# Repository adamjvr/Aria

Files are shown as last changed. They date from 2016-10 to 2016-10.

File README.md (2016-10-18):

# Aria
ARM Cortex M4F + WiFi + MPPT Solar Battery Powered module, mBed and Arduino Compatible hardware development platform.
- ARM Cortex M4F 180MHZ STM32F446RET6
- ESP8285 WiFi SoC w/ PCB Antenna
- WiFi
- USB 2.0 Connectivity
- Plenty or GPIO/Serial via the STM32
- Over the air programming and updating
- Lithium Ion Battery Power
- MPPT Solar battery charging
- USB bus power for desktop development
- Over the Air Programming
- Low power
- 2 Year Battery Life w/Single Cell Lithium Battery

Aria 0.1a PCB
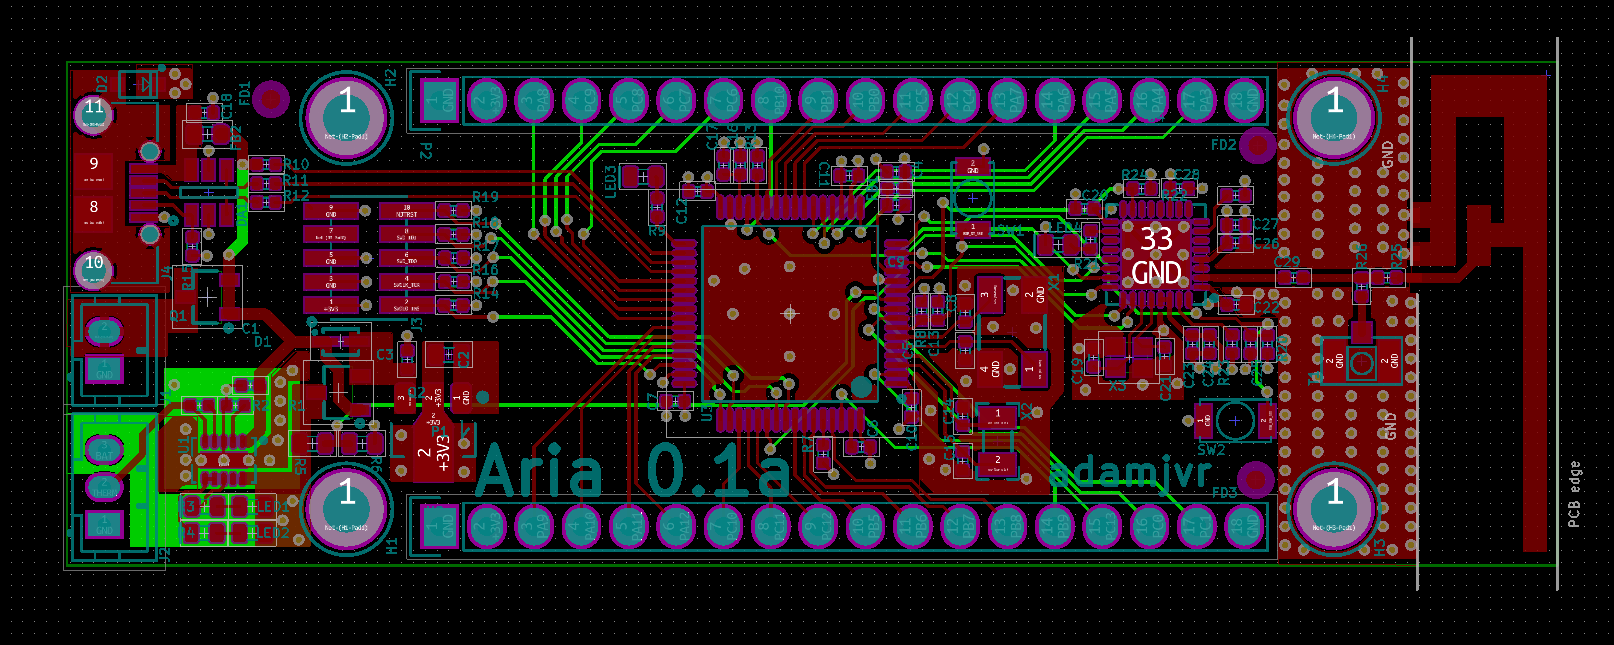
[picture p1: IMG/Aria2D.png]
Aria 0.1a KiCAD PCB

Aria 0.1a 3D Render of PCB
Top
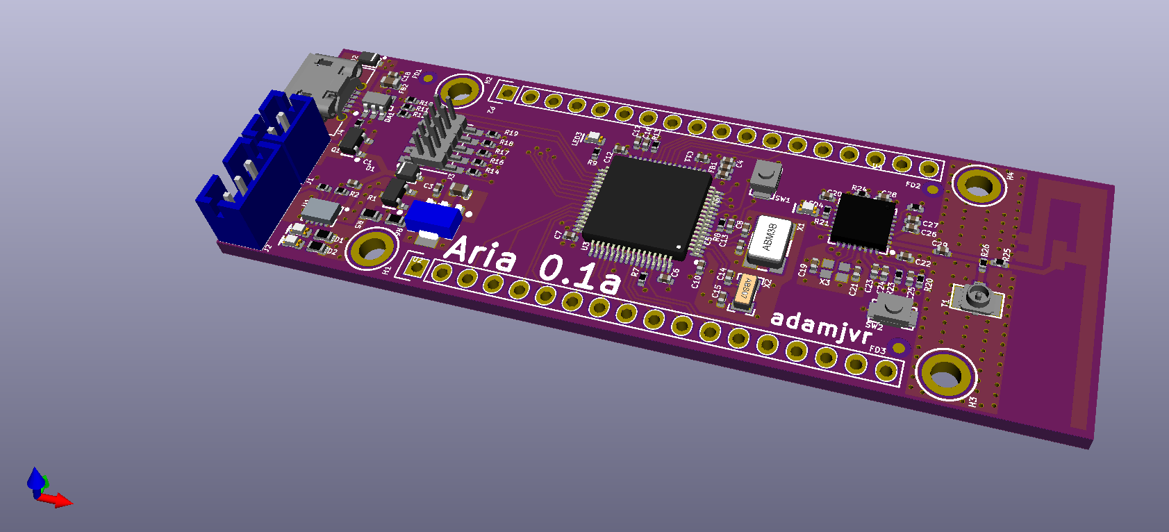
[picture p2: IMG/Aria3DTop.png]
Aria 0.1a KiCAD 3D Top

Bottom
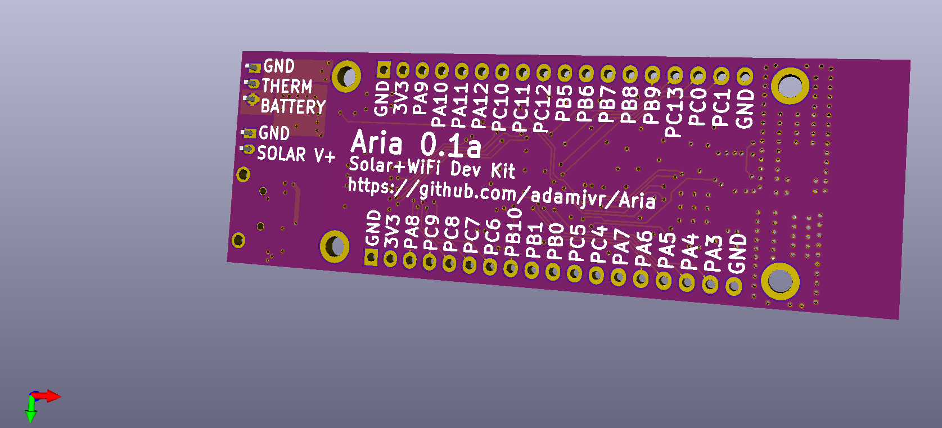
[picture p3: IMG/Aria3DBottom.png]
Aria 0.1a KiCAD 3D Bottom

Aria 0.1a ESP-12E Version PCB
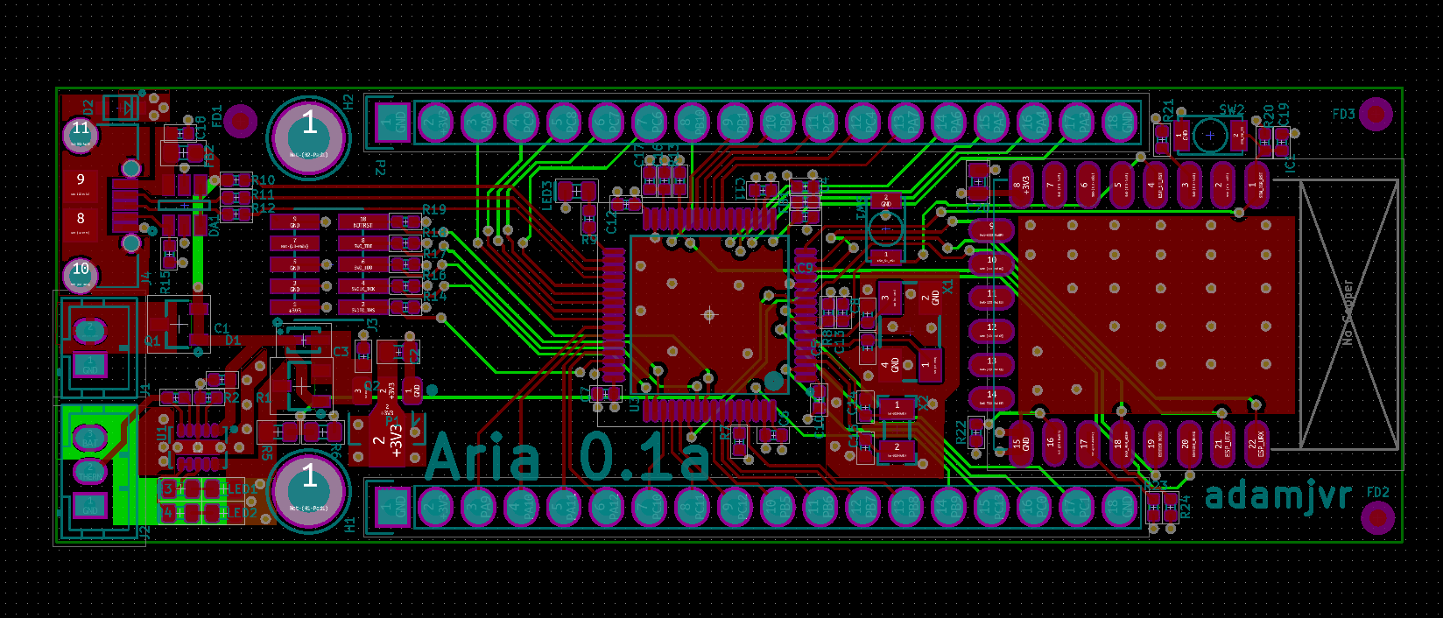
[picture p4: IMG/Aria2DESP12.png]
Aria 0.1a ESP-12E KiCAD PCB


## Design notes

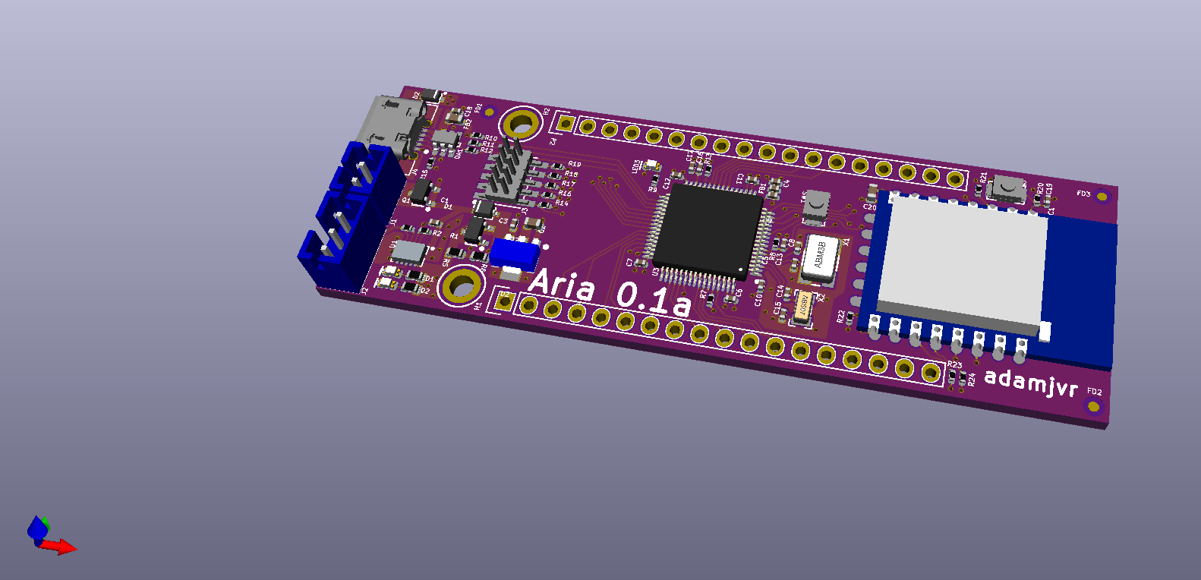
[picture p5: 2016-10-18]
IMG/Aria3DESP12.png

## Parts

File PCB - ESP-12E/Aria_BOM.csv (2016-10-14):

Id | Designator | Package | Quantity | Designation | Supplier and ref
1 | ANT1 | PCB_IF_ANT_2.4G | 1 | Inverted_F_PCB_Antenna
2 | R26,R25 | R0402 | 2 | ERJ-2GE0R00X
3 | R24,R7,R10,R13 | R0402 | 4 | RC1005F103CS
4 | P1,P2 | Socket_Strip_Straight_1x18 | 2 | CONN_01X18
5 | U1 | BQ24210 | 1 | BQ24210DQCT
6 | D1 | BAT20JFILM | 1 | BAT20JFILM
7 | Q1,Q2 | DMG2307L-7 | 2 | DMG2307L-7
8 | X2 | ABS07-32.768KHZ-9-T | 1 | ABS07-32.768KHZ-9-T
9 | D2 | RSB39VTE-17 | 1 | RSB39VTE-17
10 | DA1 | ESDA6V1BC6 | 1 | ESDA6V1BC6
11 | X1 | ABM3B8.000MHZB2T | 1 | ABM3B8.000MHZB2T
12 | FD1,FD2,FD3 | FIDUCIAL | 3 | FIDUCIAL
13 | H2,H4,H1,H3 | M2.5_HOLE | 4 | M2.5_Hole
14 | U3 | STM32F446RET6 | 1 | STM32F446RET6_-_TQFP64
15 | U4 | ESP8285 | 1 | ESP8285
16 | C1,C2 | C0402 | 2 | CL05A105KA5NQNC
17 | C3 | C0603 | 1 | CL10A106KQ8NNNC
18 | C4,C6,C7,C9,C10,C11,C12,C13,C17,C18,C20,C22,C23,C24,C25,C26,C27,C28 | C0402 | 18 | CL05B104JP5NNNC
19 | C5,C8,C19,C21 | C0402 | 4 | CL05C090CB5NNNC
20 | C14,C15 | C0402 | 2 | CL05C180GB5NCNC
21 | C16 | C0402 | 1 | CL05A475KQ5NRNC
22 | FB1 | BLM15HG601SN1D | 1 | BLM15HG601SN1D
23 | FB2 | MI0603K300R-10 | 1 | MI0603K300R-10
24 | J1 | B2B-PH-K-S(LF)(SN) | 1 | B2B-PH-K-S(LF)(SN)
25 | J2 | B3B-PH-K-S(LF)(SN) | 1 | B3B-PH-K-S(LF)(SN)
26 | J3 | 20021121-00010C4LF | 1 | 20021121-00010C4LF
27 | J4 | 0475890001 | 1 | 0475890001-MicroUSBPort
28 | LED1 | LED0603 | 1 | LTST-C191KGKT
29 | LED2 | LED0603 | 1 | LTST-C191KFKT
30 | LED3,LED4 | LED0603 | 2 | LTST-C193TBKT-5A
31 | R1 | R0402 | 1 | RC1005F4870CS
32 | R2,R8,R9,R14,R16,R17,R18,R19,R20,R21 | R0402 | 10 | RC1005F102CS
33 | R3,R4 | R0603 | 2 | RC1608J202CS
34 | R5,R6 | R0603 | 2 | ERA-3AEB3741V
35 | R11,R12 | R0402 | 2 | CPF0402B22RE1
36 | R15 | R0402 | 1 | RC1005J473CS
37 | R22,R23 | R0402 | 2 | RC1005F123CS
38 | SW1,SW2 | B3U-1000P | 2 | B3U-1000P
39 | T1 | 1909763-1 | 1 | 1909763-1
40 | U2 | AZ1117CR-3.3TRG1 | 1 | AZ1117CR-3.3TRG1_1
41 | X3 | FA-128_26.0000MF10Z-AC3 | 1 | FA-128_26.0000MF10Z-AC3

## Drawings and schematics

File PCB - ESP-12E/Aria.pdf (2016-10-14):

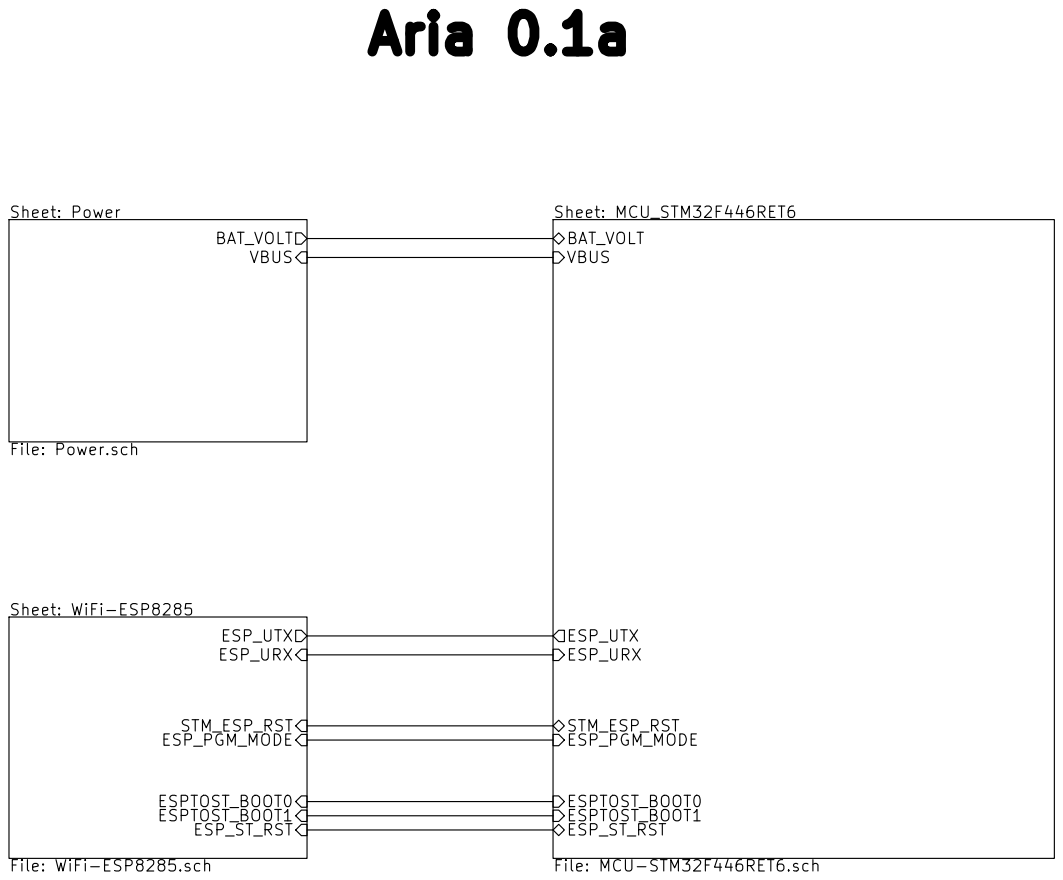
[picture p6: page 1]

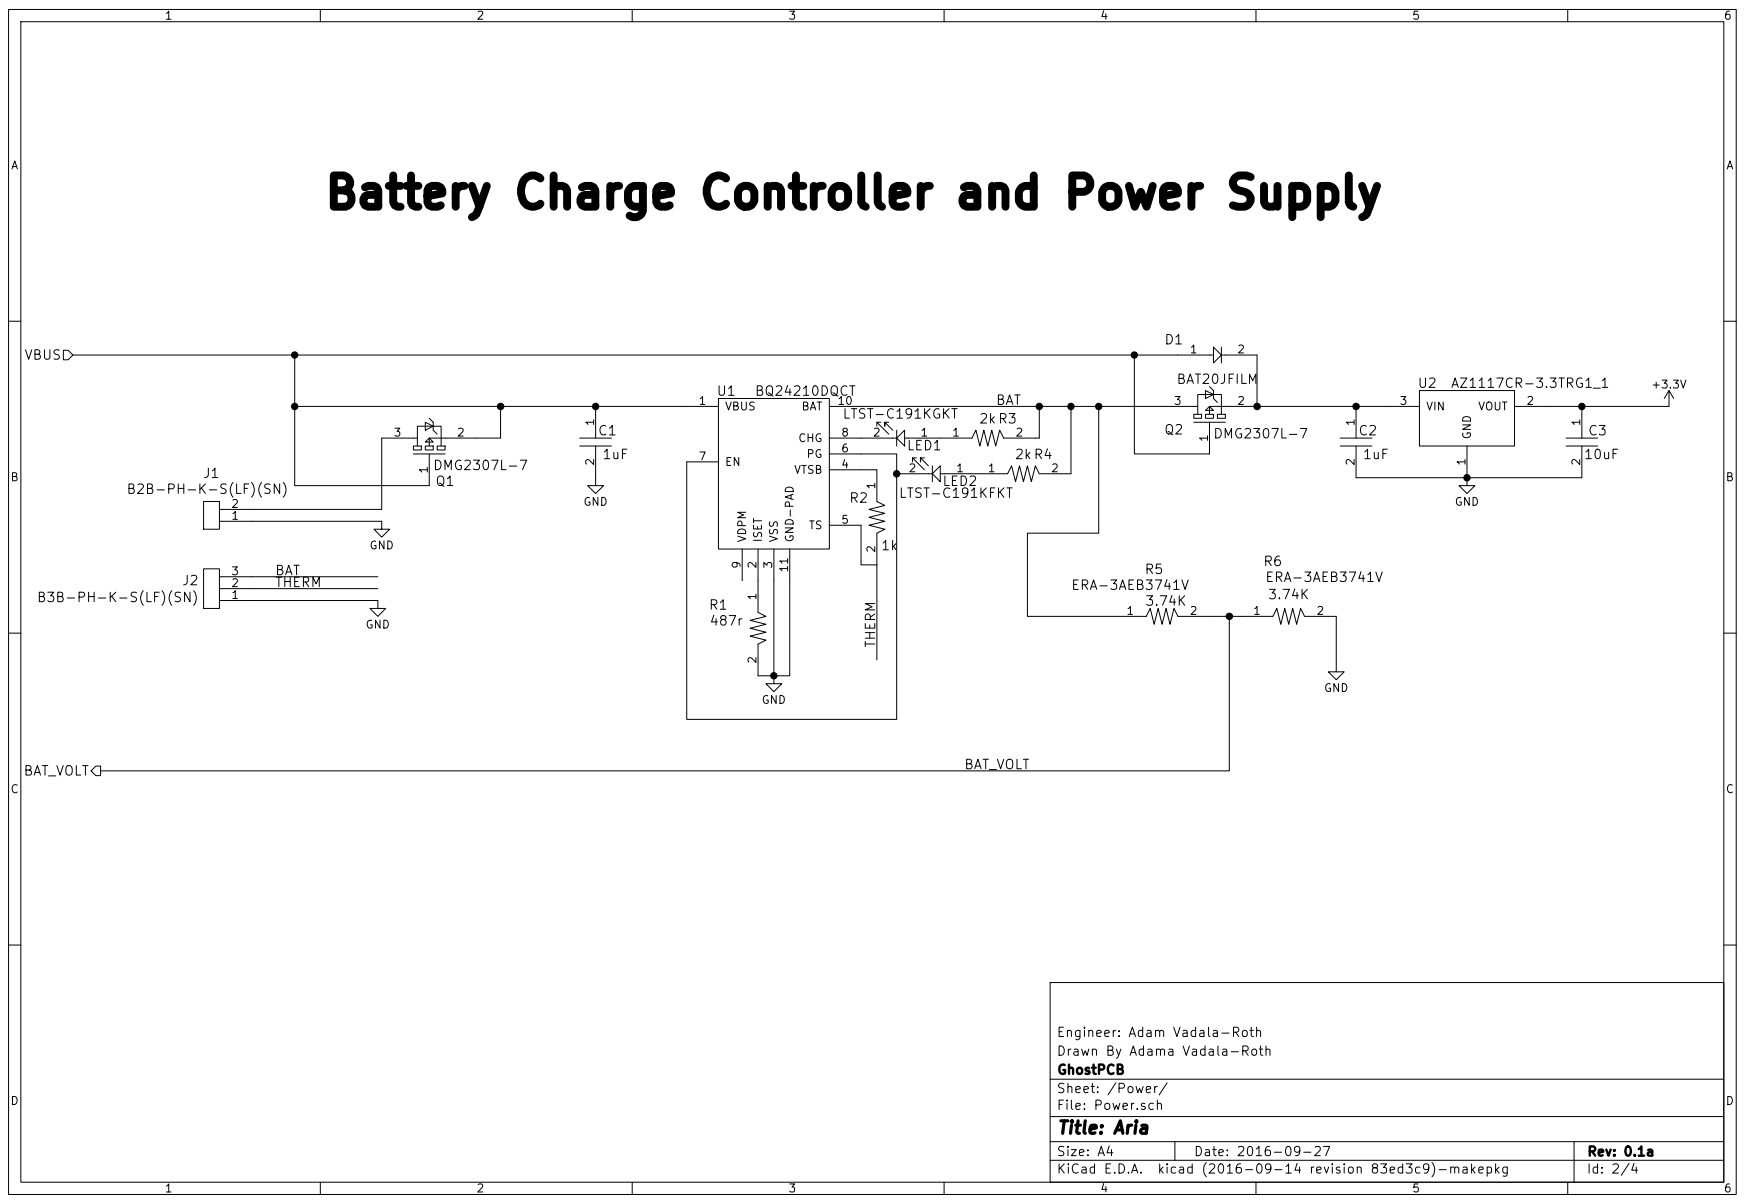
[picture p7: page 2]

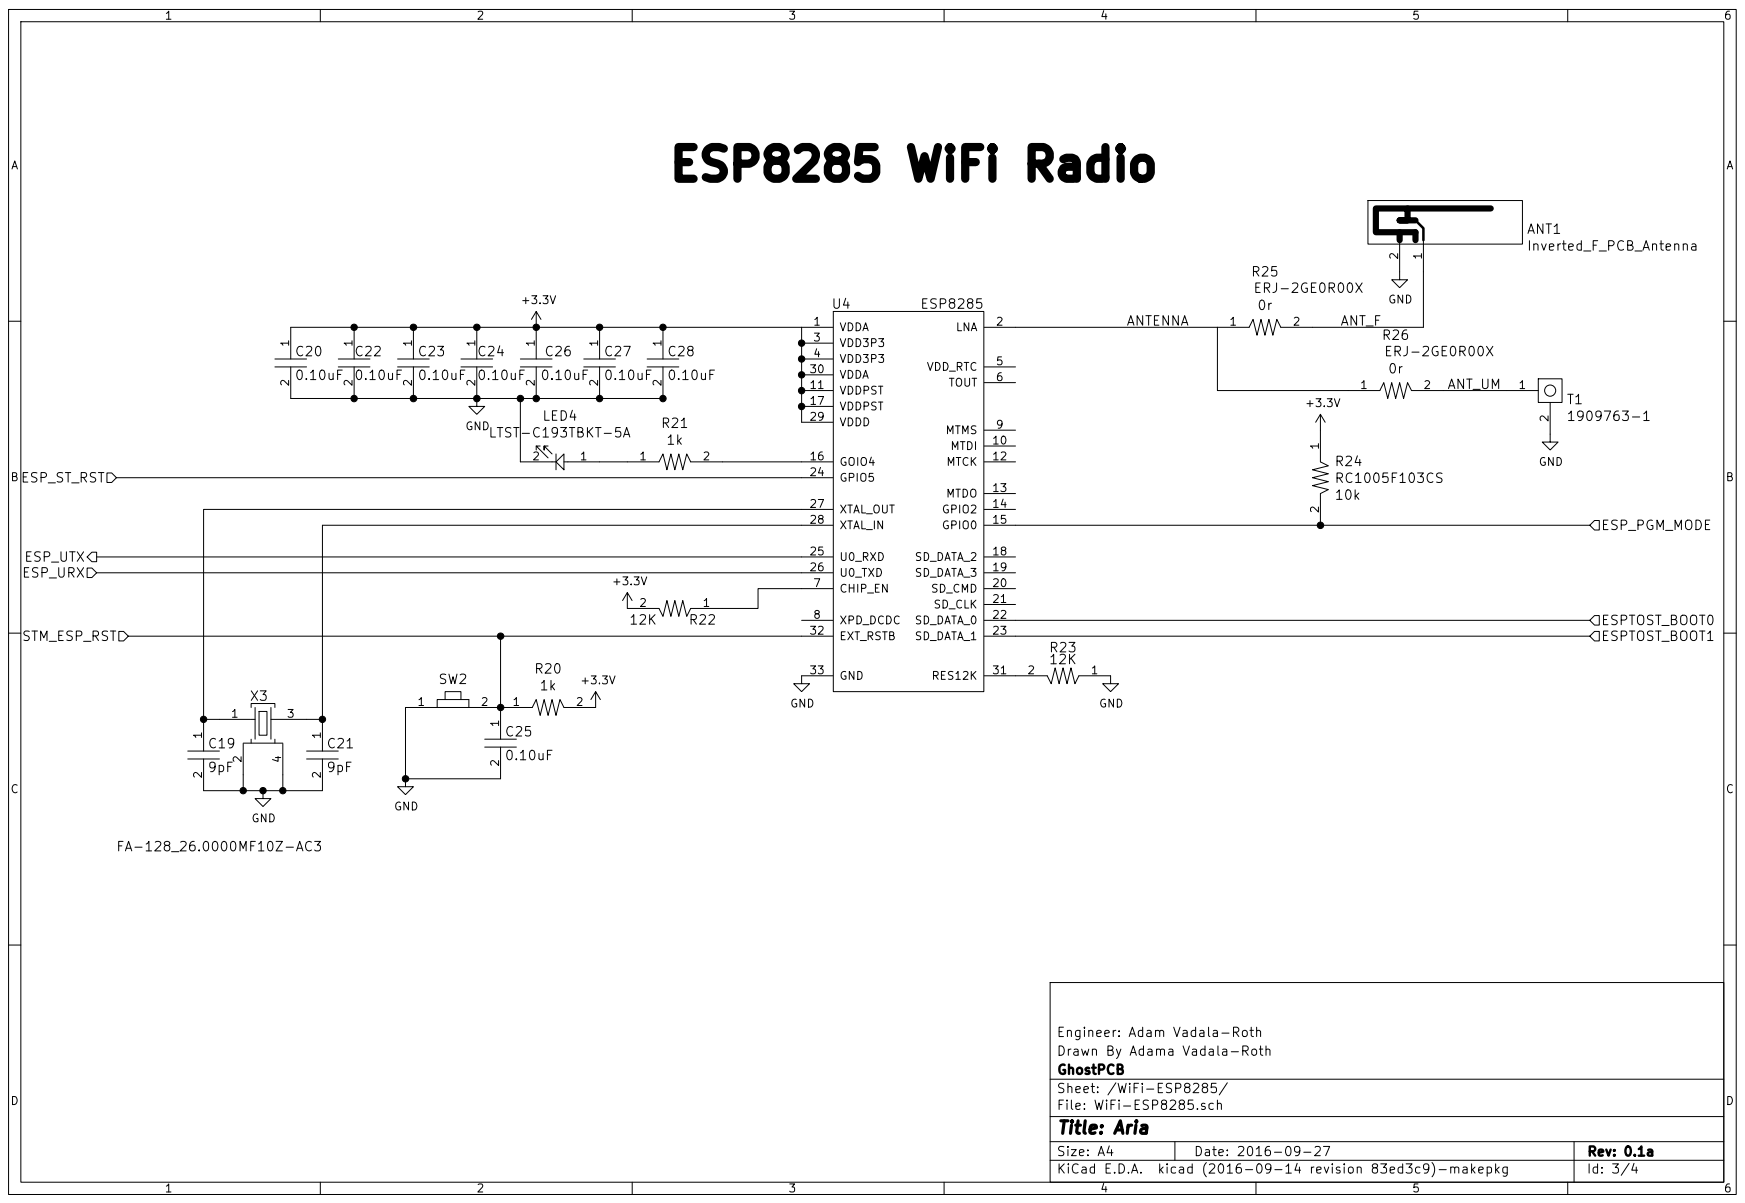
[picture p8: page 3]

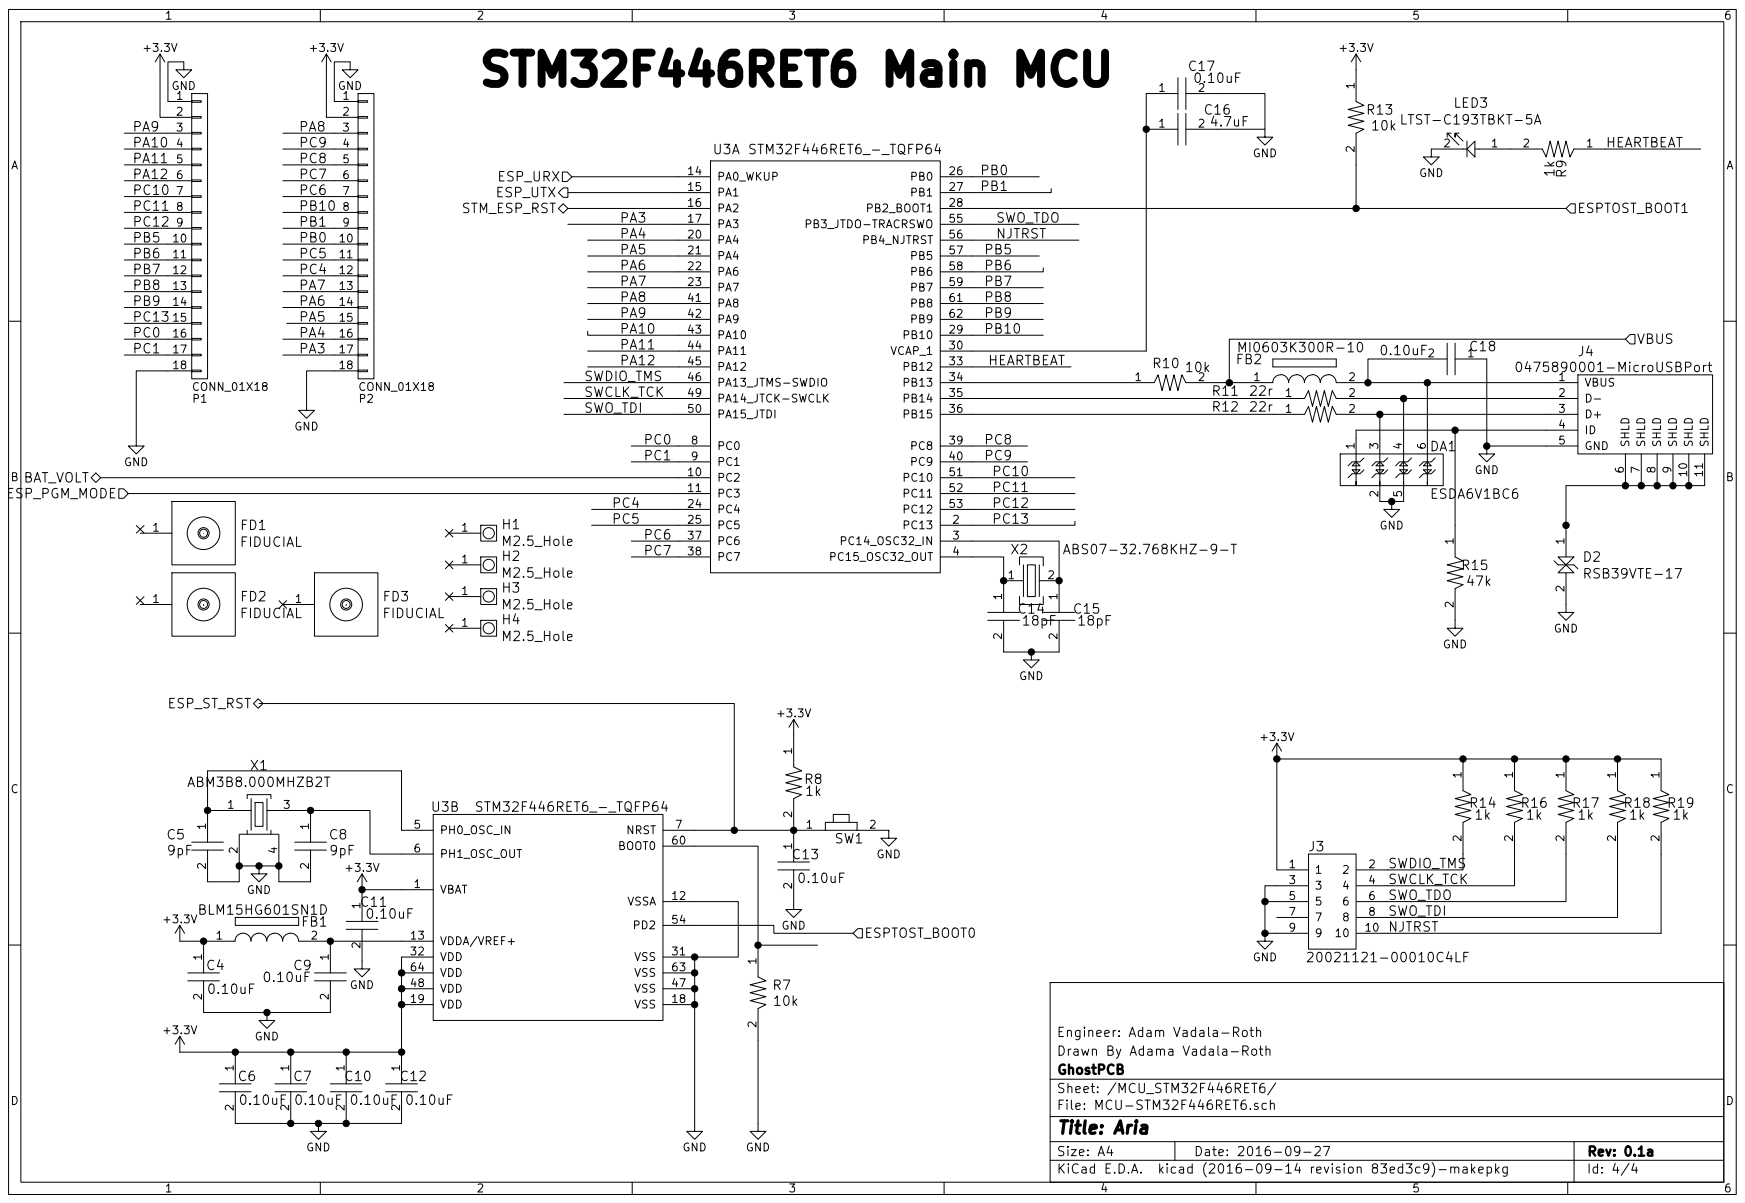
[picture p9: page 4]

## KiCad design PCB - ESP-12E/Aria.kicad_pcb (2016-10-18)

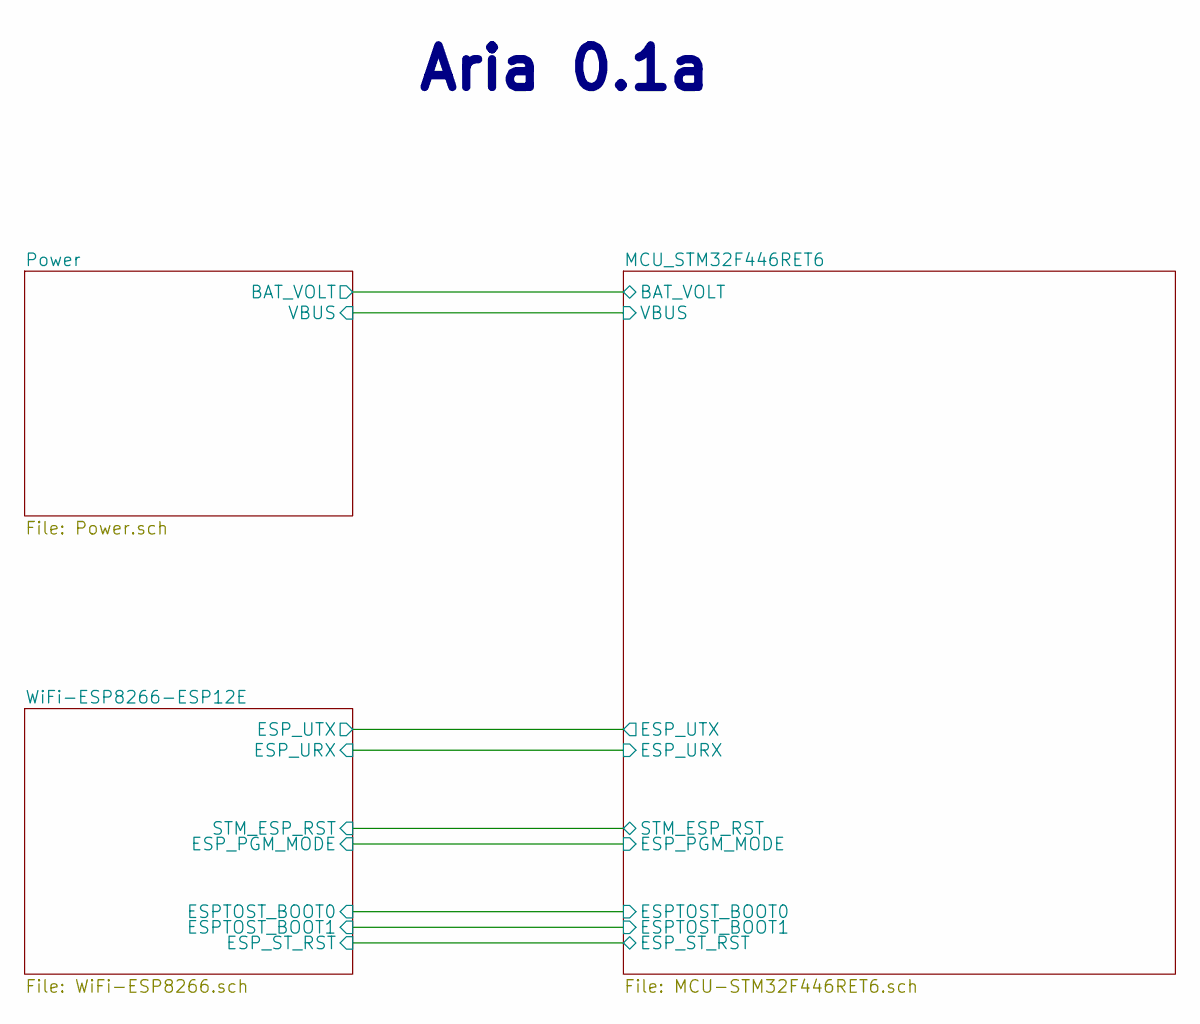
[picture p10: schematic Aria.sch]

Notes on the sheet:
Aria 0.1a

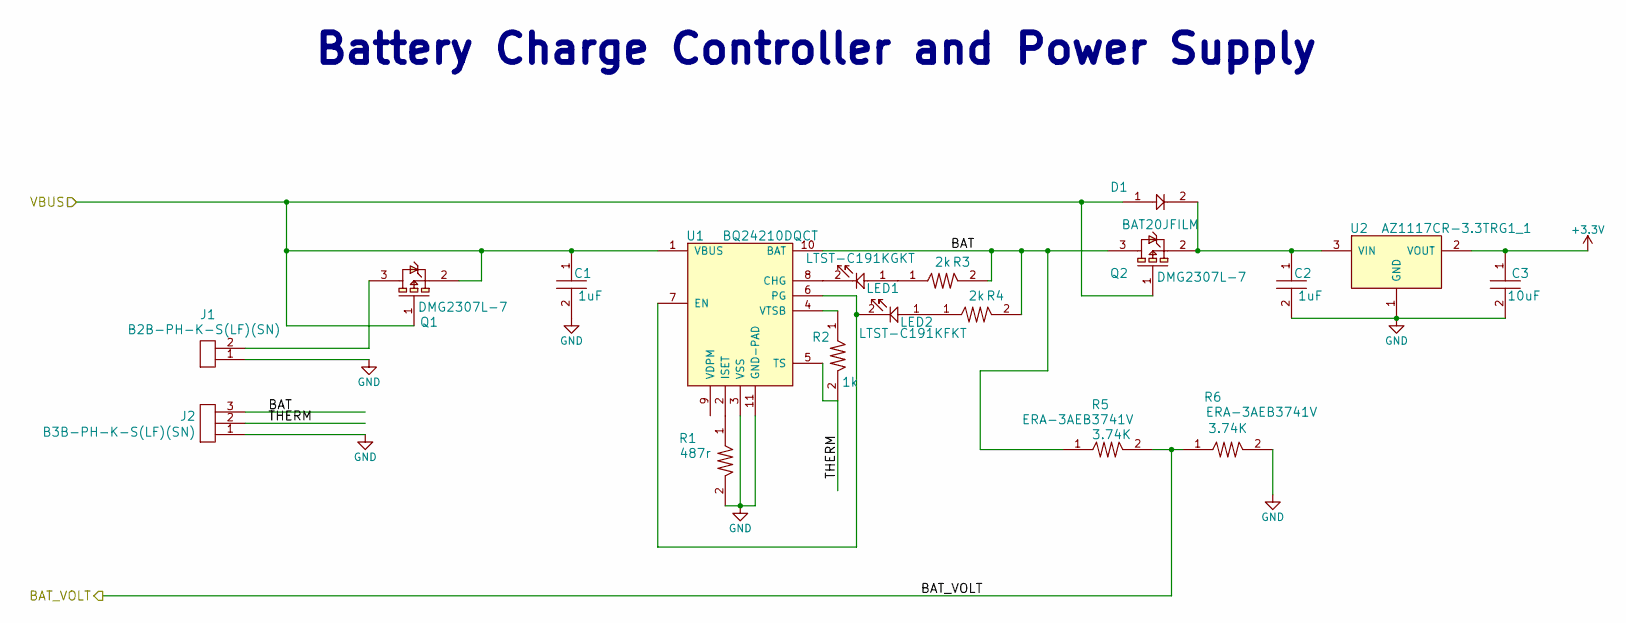
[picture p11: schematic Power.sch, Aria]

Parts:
C1, C2: CL05A105KA5NQNC; C0402; Tolerance 10%; Voltage 25V; MFR# CL05A105KA5NQNC
C3: CL10A106KQ8NNNC; C0603; Tolerance 10%; Voltage 6.3V; MFR# CL10A106KQ8NNNC
D1: BAT20JFILM; Tolerance N/A; Voltage N/A; MFR# BAT20JFILM
J1: B2B-PH-K-S(LF)(SN); Tolerance N/A; Voltage N/A; MFR# B2B-PH-K-S(LF)(SN)
J2: B3B-PH-K-S(LF)(SN); Tolerance N/A; Voltage N/A; MFR# B3B-PH-K-S(LF)(SN)
LED1: LTST-C191KGKT; LED0603; Tolerance N/A; Voltage N/A; MFR# LTST-C191KGKT
LED2: LTST-C191KFKT; LED0603; Tolerance N/A; Voltage N/A; MFR# LTST-C191KFKT
Q1, Q2: DMG2307L-7; Tolerance N/A; Voltage 30V; MFR# DMG2307L-7
R1: RC1005F4870CS; R0402; Tolerance 1%; Voltage N/A; MFR# RC1005F4870CS
R2: RC1005F102CS; R0402; Tolerance %; Voltage N/A; MFR# RC1005F102CS
R3, R4: RC1608J202CS; R0603; Tolerance 1%; Voltage N/A; MFR# RC1608F202CS
R5, R6: ERA-3AEB3741V; R0603; Tolerance 1%; Voltage N/A; MFR# ERA-3AEB3741V
U1: BQ24210DQCT; BQ24210; Tolerance N/A; Voltage 3.5-18VDC; MFR# BQ24210DQCT
U2: AZ1117CR-3.3TRG1_1; AZ1117CR-3.3TRG1; Tolerance N/A; Voltage 3.7V input 3.3V Output; MFR# AZ1117CR-3.3TRG1

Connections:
+3V3: C3.1, U2.2 (VOUT); also elsewhere on the board
/MCU_STM32F446RET6/BAT_VOLT: R5.2, R6.1; also elsewhere on the board
/MCU_STM32F446RET6/VBUS: C1.1, D1.1, Q1.1, Q1.2, Q2.1, U1.1 (VBUS); also elsewhere on the board
/Power/BAT: J2.3, Q2.3, R3.2, R4.2, R5.1, U1.10 (BAT)
/Power/THERM: J2.2, R2.2, U1.5 (TS)
GND: C1.2, C2.2, C3.2, J1.1, J2.1, R1.2, R6.2, U1.3 (VSS), U1.11 (GND-PAD), U2.1 (GND); also elsewhere on the board
unnamed: C2.1, D1.2, Q2.2, U2.3 (VIN)
unnamed: J1.2, Q1.3
unnamed: LED1.1, R3.1
unnamed: LED1.2, U1.8 (CHG)
unnamed: LED2.1, R4.1
unnamed: LED2.2, U1.6 (PG), U1.7 (EN)
unnamed: R1.1, U1.2 (ISET)
unnamed: R2.1, U1.4 (VTSB)

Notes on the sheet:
Battery Charge Controller and Power Supply

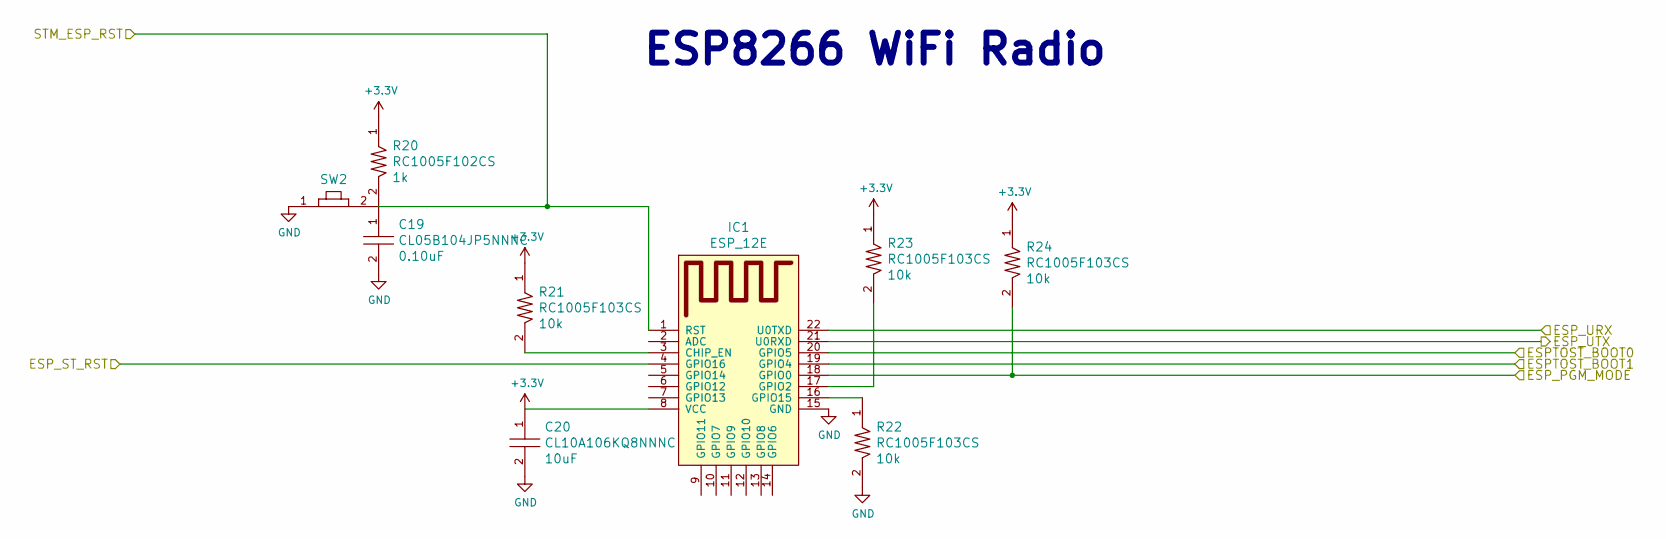
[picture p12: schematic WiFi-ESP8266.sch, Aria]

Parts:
C19: CL05B104JP5NNNC; C0402; Tolerance 5%; Voltage 10V; MFR# CL05B104JP5NNNC
C20: CL10A106KQ8NNNC; C0603; Tolerance 10%; Voltage 6.3V; MFR# CL10A106KQ8NNNC
IC1: ESP_12E; ESP-12E
R20: RC1005F102CS; R0402; Tolerance %; Voltage N/A; MFR# RC1005F102CS
R21, R22, R23, R24: RC1005F103CS; R0402; Tolerance 1%; Voltage N/A; MFR# RC1005F103CS
SW2: B3U-1000P; Tolerance %; Voltage 50V; MFR# B3U-1000P

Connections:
+3V3: C20.1, IC1.8 (VCC), R20.1, R21.1, R23.1, R24.1; also elsewhere on the board
/MCU_STM32F446RET6/ESPTOST_BOOT0: IC1.20 (GPIO5); also elsewhere on the board
/MCU_STM32F446RET6/ESPTOST_BOOT1: IC1.19 (GPIO4); also elsewhere on the board
/MCU_STM32F446RET6/ESP_PGM_MODE: IC1.18 (GPIO0), R24.2; also elsewhere on the board
/MCU_STM32F446RET6/ESP_ST_RST: IC1.4 (GPIO16); also elsewhere on the board
/MCU_STM32F446RET6/ESP_URX: IC1.22 (U0TXD); also elsewhere on the board
/MCU_STM32F446RET6/ESP_UTX: IC1.21 (U0RXD); also elsewhere on the board
/MCU_STM32F446RET6/STM_ESP_RST: C19.1, IC1.1 (RST), R20.2, SW2.2; also elsewhere on the board
GND: C19.2, C20.2, IC1.15 (GND), R22.2, SW2.1; also elsewhere on the board
unnamed: IC1.3 (CHIP_EN), R21.2
unnamed: IC1.16 (GPIO15), R22.1
unnamed: IC1.17 (GPIO2), R23.2

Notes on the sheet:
ESP8266 WiFi Radio

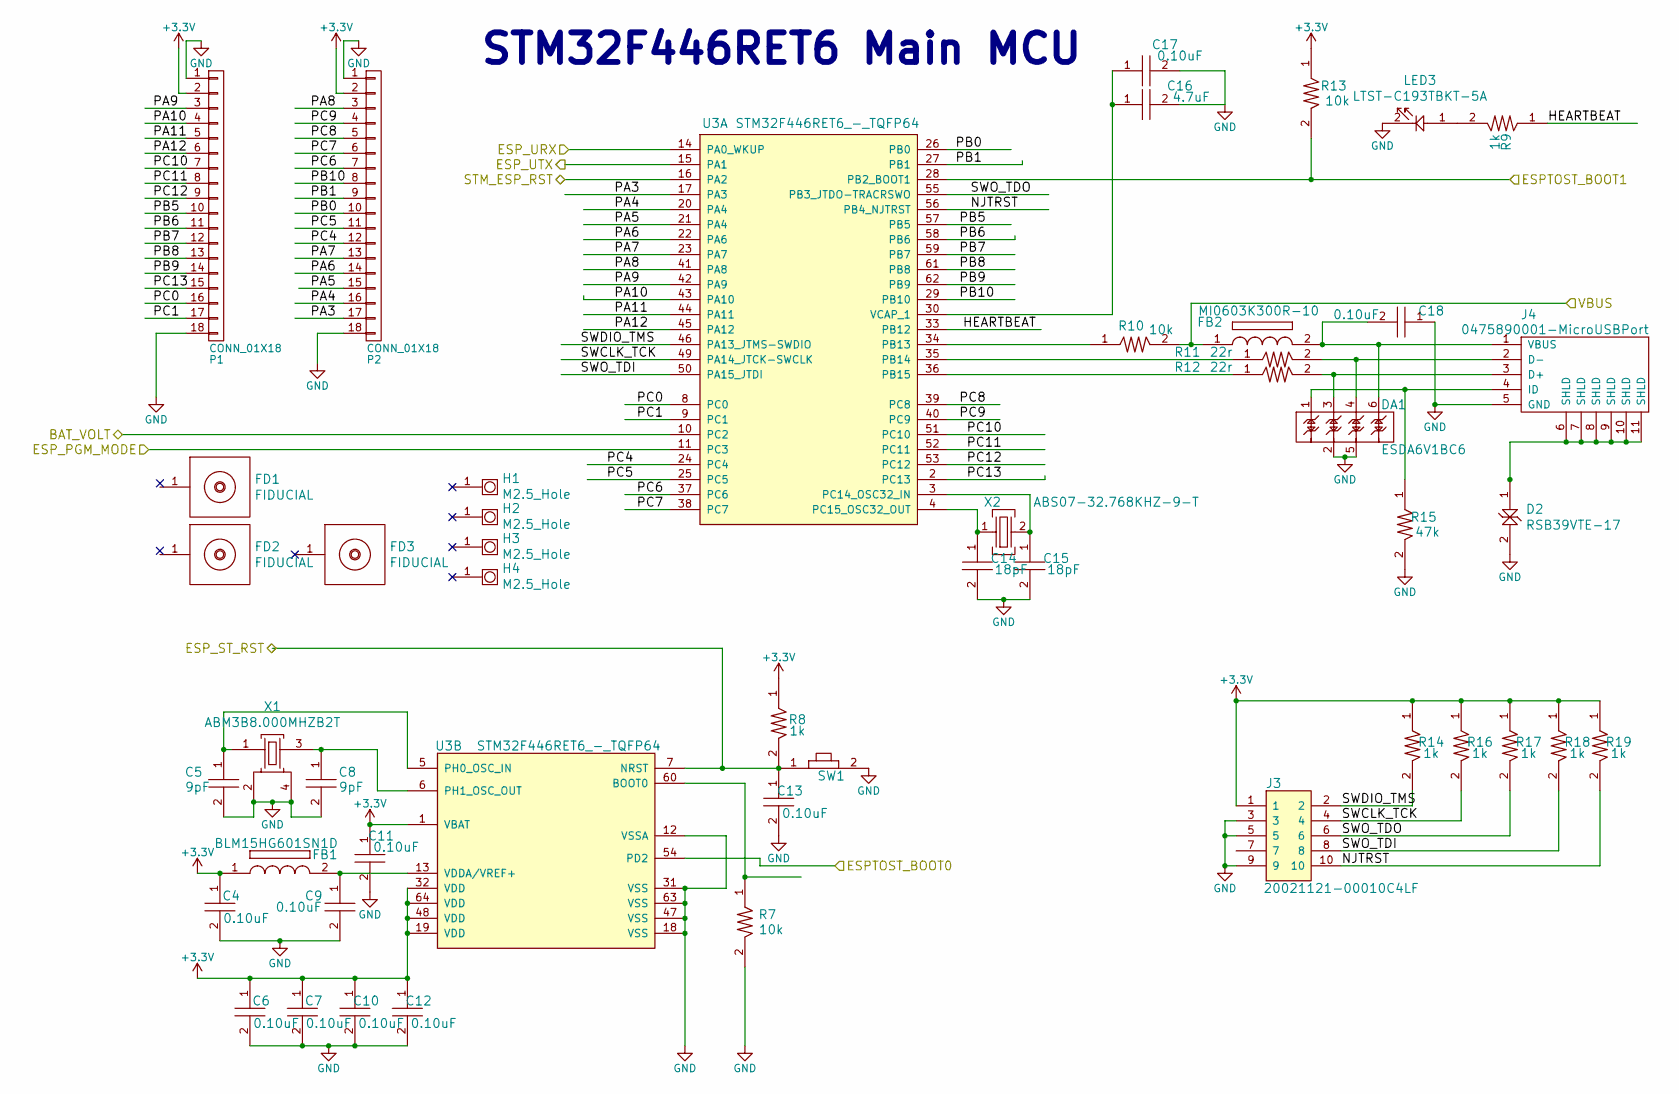
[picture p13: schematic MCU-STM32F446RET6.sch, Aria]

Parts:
C4, C6, C7, C9, C10, C11, C12, C13, C17, C18: CL05B104JP5NNNC; C0402; Tolerance 5%; Voltage 10V; MFR# CL05B104JP5NNNC
C5, C8: CL05C090CB5NNNC; C0402; Tolerance 0.25pF; Voltage 50V; MFR# CL05C090CB5NNNC
C14, C15: CL05C180GB5NCNC; C0402; Tolerance 2%; Voltage 50V; MFR# CL05C180GB5NCNC
C16: CL05A475KQ5NRNC; C0402; Tolerance 10%; Voltage 25V; MFR# CL05A475KQ5NRNC
D2: RSB39VTE-17; Tolerance N/A; Voltage 30V; MFR# RSB39VTE-17
DA1: ESDA6V1BC6; Tolerance N/A; Voltage 4V; MFR# ESDA6V1BC6
FB1: BLM15HG601SN1D; Tolerance N/A; Voltage N/A; MFR# BLM15HG601SN1D
FB2: MI0603K300R-10; Tolerance N/A; Voltage N/A; MFR# MI0603K300R-10
FD1, FD2, FD3: FIDUCIAL
H1, H2, H3, H4: M2.5_Hole; M2.5_HOLE
J3: 20021121-00010C4LF; Tolerance N/A; Voltage 200V MAX; MFR# 20021121-00010C4LF
J4: 0475890001-MicroUSBPort; 0475890001; Tolerance N/A; Voltage 5V; MFR# 0475890001
LED3: LTST-C193TBKT-5A; LED0603; Tolerance N/A; Voltage 2.8V Forward Voltage; MFR# LTST-C193TBKT-5A
P1, P2: CONN_01X18
R7, R10, R13: RC1005F103CS; R0402; Tolerance 1%; Voltage N/A; MFR# RC1005F103CS
R8, R9, R14, R16, R17, R18, R19: RC1005F102CS; R0402; Tolerance %; Voltage N/A; MFR# RC1005F102CS
R11, R12: CPF0402B22RE1; R0402; Tolerance 0.1%; Voltage N/A; MFR# CPF0402B22RE1
R15: RC1005J473CS; R0402; Tolerance 5%; Voltage N/A; MFR# RC1005J473CS
SW1: B3U-1000P; Tolerance %; Voltage 50V; MFR# B3U-1000P
U3: STM32F446RET6_-_TQFP64; STM32F446RET6; Tolerance N/A; Voltage 1.8-3.3V; MFR# STM32F446RET6
X1: ABM3B8.000MHZB2T; Tolerance N/A; Voltage 3.3V; MFR# ABM3B-8.000MHZ-B2-T
X2: ABS07-32.768KHZ-9-T; Tolerance ±20ppm; Voltage N/A; MFR# ABS07-32.768KHZ-9-T

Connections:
+3V3: C4.1, C6.1, C7.1, C10.1, C11.1, C12.1, FB1.1, J3.1, P1.2, P2.2, R8.1, R13.1, R14.1, R16.1, R17.1, R18.1, R19.1, U3.1 (VBAT), U3.19 (VDD), U3.32 (VDD), U3.48 (VDD), U3.64 (VDD); also elsewhere on the board
/MCU_STM32F446RET6/BAT_VOLT: U3.10 (PC2); also elsewhere on the board
/MCU_STM32F446RET6/ESPTOST_BOOT0: U3.54 (PD2); also elsewhere on the board
/MCU_STM32F446RET6/ESPTOST_BOOT1: R13.2, U3.28 (PB2_BOOT1); also elsewhere on the board
/MCU_STM32F446RET6/ESP_PGM_MODE: U3.11 (PC3); also elsewhere on the board
/MCU_STM32F446RET6/ESP_ST_RST: C13.1, R8.2, SW1.1, U3.7 (NRST); also elsewhere on the board
/MCU_STM32F446RET6/ESP_URX: U3.14 (PA0_WKUP); also elsewhere on the board
/MCU_STM32F446RET6/ESP_UTX: U3.15 (PA1); also elsewhere on the board
/MCU_STM32F446RET6/HEARTBEAT: R9.1, U3.33 (PB12)
/MCU_STM32F446RET6/NJTRST: J3.10, R19.2, U3.56 (PB4_NJTRST)
/MCU_STM32F446RET6/PA3: P2.17, U3.17 (PA3)
/MCU_STM32F446RET6/PA4: P2.16, U3.20 (PA4)
/MCU_STM32F446RET6/PA5: P2.15, U3.21 (PA4)
/MCU_STM32F446RET6/PA6: P2.14, U3.22 (PA6)
/MCU_STM32F446RET6/PA7: P2.13, U3.23 (PA7)
/MCU_STM32F446RET6/PA8: P2.3, U3.41 (PA8)
/MCU_STM32F446RET6/PA9: P1.3, U3.42 (PA9)
/MCU_STM32F446RET6/PA10: P1.4, U3.43 (PA10)
/MCU_STM32F446RET6/PA11: P1.5, U3.44 (PA11)
/MCU_STM32F446RET6/PA12: P1.6, U3.45 (PA12)
/MCU_STM32F446RET6/PB0: P2.10, U3.26 (PB0)
/MCU_STM32F446RET6/PB1: P2.9, U3.27 (PB1)
/MCU_STM32F446RET6/PB5: P1.10, U3.57 (PB5)
/MCU_STM32F446RET6/PB6: P1.11, U3.58 (PB6)
/MCU_STM32F446RET6/PB7: P1.12, U3.59 (PB7)
/MCU_STM32F446RET6/PB8: P1.13, U3.61 (PB8)
/MCU_STM32F446RET6/PB9: P1.14, U3.62 (PB9)
/MCU_STM32F446RET6/PB10: P2.8, U3.29 (PB10)
/MCU_STM32F446RET6/PC0: P1.16, U3.8 (PC0)
/MCU_STM32F446RET6/PC1: P1.17, U3.9 (PC1)
/MCU_STM32F446RET6/PC4: P2.12, U3.24 (PC4)
/MCU_STM32F446RET6/PC5: P2.11, U3.25 (PC5)
/MCU_STM32F446RET6/PC6: P2.7, U3.37 (PC6)
/MCU_STM32F446RET6/PC7: P2.6, U3.38 (PC7)
/MCU_STM32F446RET6/PC8: P2.5, U3.39 (PC8)
/MCU_STM32F446RET6/PC9: P2.4, U3.40 (PC9)
/MCU_STM32F446RET6/PC10: P1.7, U3.51 (PC10)
/MCU_STM32F446RET6/PC11: P1.8, U3.52 (PC11)
/MCU_STM32F446RET6/PC12: P1.9, U3.53 (PC12)
/MCU_STM32F446RET6/PC13: P1.15, U3.2 (PC13)
/MCU_STM32F446RET6/STM_ESP_RST: U3.16 (PA2); also elsewhere on the board
/MCU_STM32F446RET6/SWCLK_TCK: J3.4, R16.2, U3.49 (PA14_JTCK-SWCLK)
/MCU_STM32F446RET6/SWDIO_TMS: J3.2, R14.2, U3.46 (PA13_JTMS-SWDIO)
/MCU_STM32F446RET6/SWO_TDI: J3.8, R18.2, U3.50 (PA15_JTDI)
/MCU_STM32F446RET6/SWO_TDO: J3.6, R17.2, U3.55 (PB3_JTDO-TRACRSWO)
/MCU_STM32F446RET6/VBUS: FB2.1, R10.2; also elsewhere on the board
GND: C4.2, C5.2, C6.2, C7.2, C8.2, C9.2, C10.2, C11.2, C12.2, C13.2, C14.2, C15.2, C16.2, C17.2, C18.1, D2.2, DA1.2, DA1.5, J3.3, J3.5, J3.9, J4.5 (GND), LED3.2, P1.1, P1.18, P2.1, P2.18, R7.2, R15.2, SW1.2, U3.12 (VSSA), U3.18 (VSS), U3.31 (VSS), U3.47 (VSS), U3.63 (VSS), X1.2, X1.4; also elsewhere on the board
unnamed: C5.1, U3.5 (PH0_OSC_IN), X1.1
unnamed: C8.1, U3.6 (PH1_OSC_OUT), X1.3
unnamed: C9.1, FB1.2, U3.13 (VDDA/VREF+)
unnamed: C14.1, U3.4 (PC15_OSC32_OUT), X2.1
unnamed: C15.1, U3.3 (PC14_OSC32_IN), X2.2
unnamed: C16.1, C17.1, U3.30 (VCAP_1)
unnamed: C18.2, DA1.6, FB2.2, J4.1 (VBUS)
unnamed: D2.1, J4.6 (SHLD), J4.7 (SHLD), J4.8 (SHLD), J4.9 (SHLD), J4.10 (SHLD), J4.11 (SHLD)
unnamed: DA1.1, J4.4 (ID), R15.1
unnamed: DA1.3, J4.3 (D+), R12.2
unnamed: DA1.4, J4.2 (D-), R11.2
unnamed: LED3.1, R9.2
unnamed: R7.1, U3.60 (BOOT0)
unnamed: R10.1, U3.34 (PB13)
unnamed: R11.1, U3.35 (PB14)
unnamed: R12.1, U3.36 (PB15)

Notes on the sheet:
STM32F446RET6 Main MCU

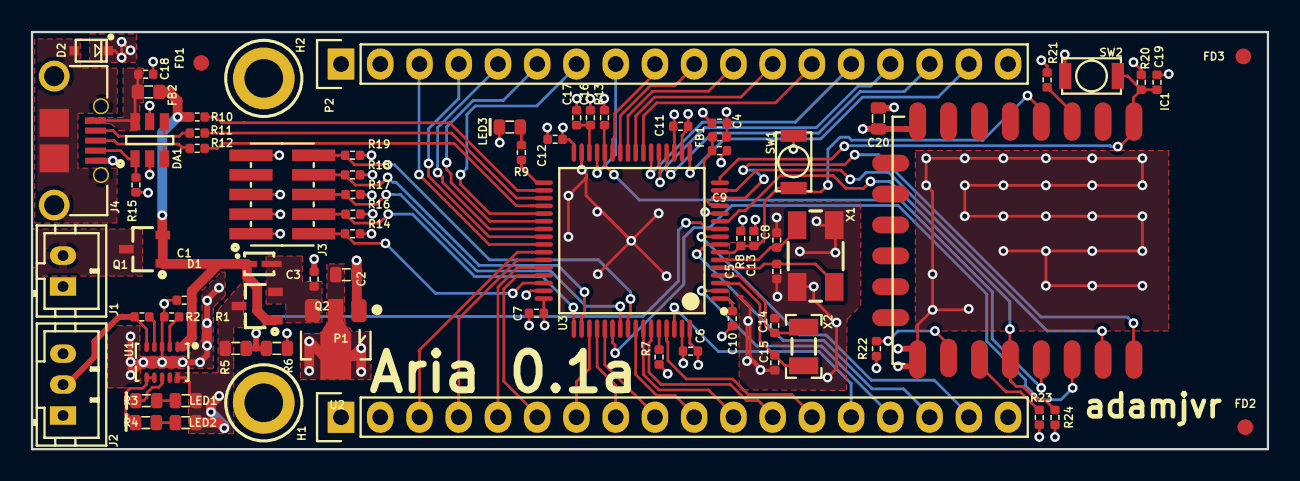
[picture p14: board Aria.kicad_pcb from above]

Board: 4 copper layers, 80.0 x 27.0 mm, 73 parts (0 on the bottom side), 76 nets.

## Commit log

2016-09-27 Schematic
    Schematic 90% complete, and Board layout started. Next update schematic
    should be solidified and board layout near complete.
    [Aria.kicad_pcb, Aria.sch, MCU-STM32F446RET6.sch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]
2016-09-29 Board Layout
    Board layout started. ESP8285 component placement preliminary complete.
    3D parts added and updated for ESP8285. STM32 and SOT32 3/6 pin
    packages.
    [Aria.kicad_pcb, MCU-STM32F446RET6.sch, WiFi-ESP8285.sch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]
2016-09-29 Preliminary Formfactor
    Preliminary formfactor designed. component placelement still underway
    [Aria.kicad_pcb, MCU-STM32F446RET6.sch, Power.sch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]
2016-09-29 Finished Placement and Mapping
    Components placed, some routing completed. pin header mapping figured
    out.
    [Aria.kicad_pcb, Aria.sch, MCU-STM32F446RET6.sch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]
2016-09-30 Layout
    layout underway, one side completely routed, next other side, ESP, and
    PCB antenna. Added PDF for app not on 2.4GHZ antenna similar to the one
    sparkfun uses in their thing boards, I suspect this is where they got it
    and it seems reliable.
    [Aria.kicad_pcb, _saved_MCU-STM32F446RET6.sch]
2016-10-02 Board Size. Routing and Antenna
    Board Size tweaked. More signals routed. Next will be pin swapping and
    routing finished. Also experimented with importing a PCB antenna design
    from bitmap, still can't get it quite right, hopefully nex commit.
    [Aria.kicad_pcb, MCU-STM32F446RET6.sch, WiFi-ESP8285.sch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]
2016-10-04 More routing
    more routing completed, but thinking of scraping the current pass
    entirely and rechoosing all the pins.
    [Aria.kicad_pcb, MCU-STM32F446RET6.sch, WiFi-ESP8285.sch]
2016-10-13 Updates
    Changed board size, heavily altered schematic and pinning to be more
    efficient. Program mode for ESP8285 is switched to GPIO0 being pulled
    high 10k and toggled by STM32. Board at 30mm By 70.5mm. Also switching
    to chip antenna next commit, expect updates to libraries.
    [Aria.kicad_pcb, MCU-STM32F446RET6.sch, WiFi-ESP8285.sch]
2016-10-14 Board Finished
    Board finished
    [Aria-B.Cu.gbl, Aria-B.Mask.gbs, Aria-B.SilkS.gbo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]
2016-10-16 ESP Footprint Error and RF improvement
    ESP8285 footprint was wrong, made when I was still learning kiCAD.
    Footprint change and entire topology reconstructed and rerouted. Added
    ground pours and heavy via stitching to improve RF performance. Also
    started an ESP-12E module based variant. Both will be fabbed at the same
    time.
    [Aria-B.Cu.gbl, Aria-B.Mask.gbs, Aria-B.SilkS.gbo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]
2016-10-18 DRC Cleared and Pictures
    DRC cleared of errors for both Aria board designs. New pictures have
    been added. Readme has also been updated.
    [Aria.kicad_pcb, Aria.sch, MCU-STM32F446RET6.sch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]
2016-10-27 Switch
    Power switch added for switching board off for storage and shipping.
    Power supply circuit routing revised and updated.
    [Aria.csv, Aria.kicad_pcb, Aria.sch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]
2016-10-29 Power Switch Revision
    Power switch and power supply topology revised. New microchip LDO from
    Ventor replaces old LDO, power switch not toggles LDO shutdown enable
    for turing Aria on and off.
    [Aria.kicad_pcb, MCU-STM32F446RET6.sch, Power.sch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]
